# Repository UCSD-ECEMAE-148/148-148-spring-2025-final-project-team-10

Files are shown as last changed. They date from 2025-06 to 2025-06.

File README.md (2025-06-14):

# Autonomous Driving with Ultra-Wide Band (UWB) and Aruco Marker

<div align="center">
  <a href="https://jacobsschool.ucsd.edu/">
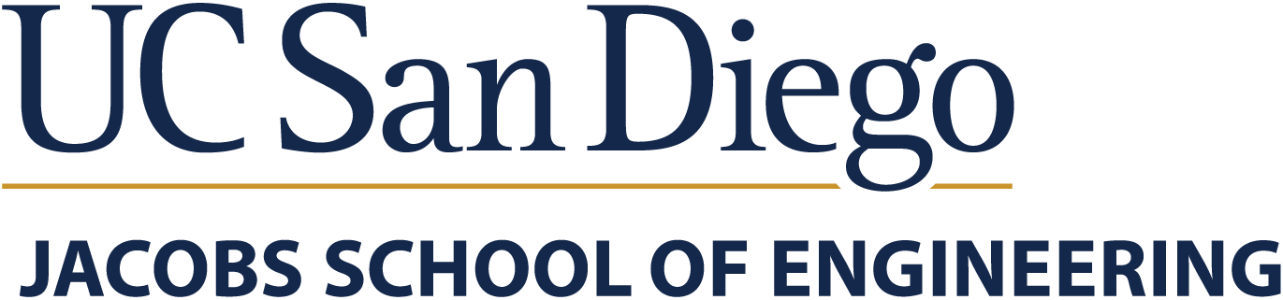
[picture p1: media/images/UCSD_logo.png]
    
  </a>
  <h3>ECE/MAE-148 Final Project</h3>
  <p>
    Spring 2025 - Team 10
  </p>
  <a>
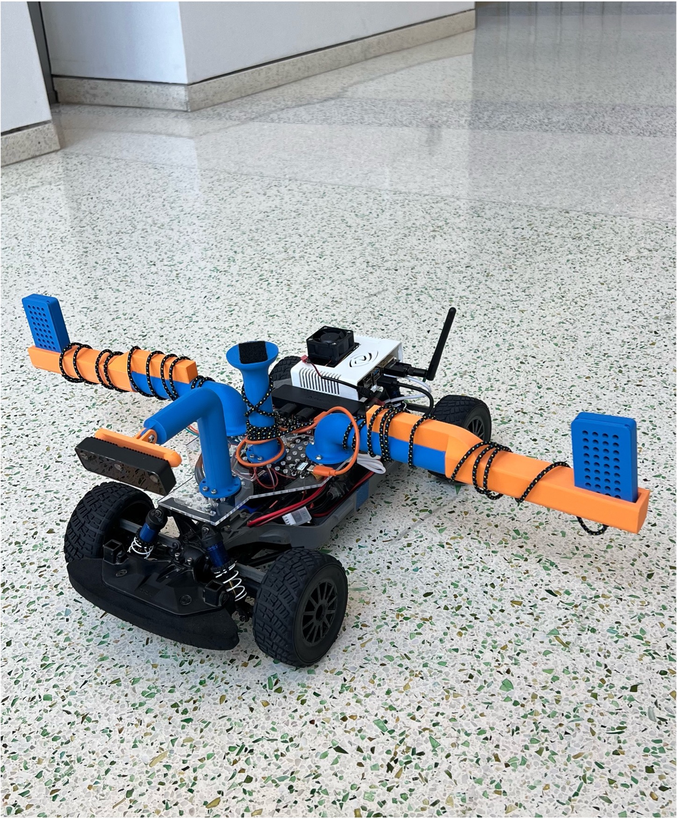
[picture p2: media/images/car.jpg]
Car View
    
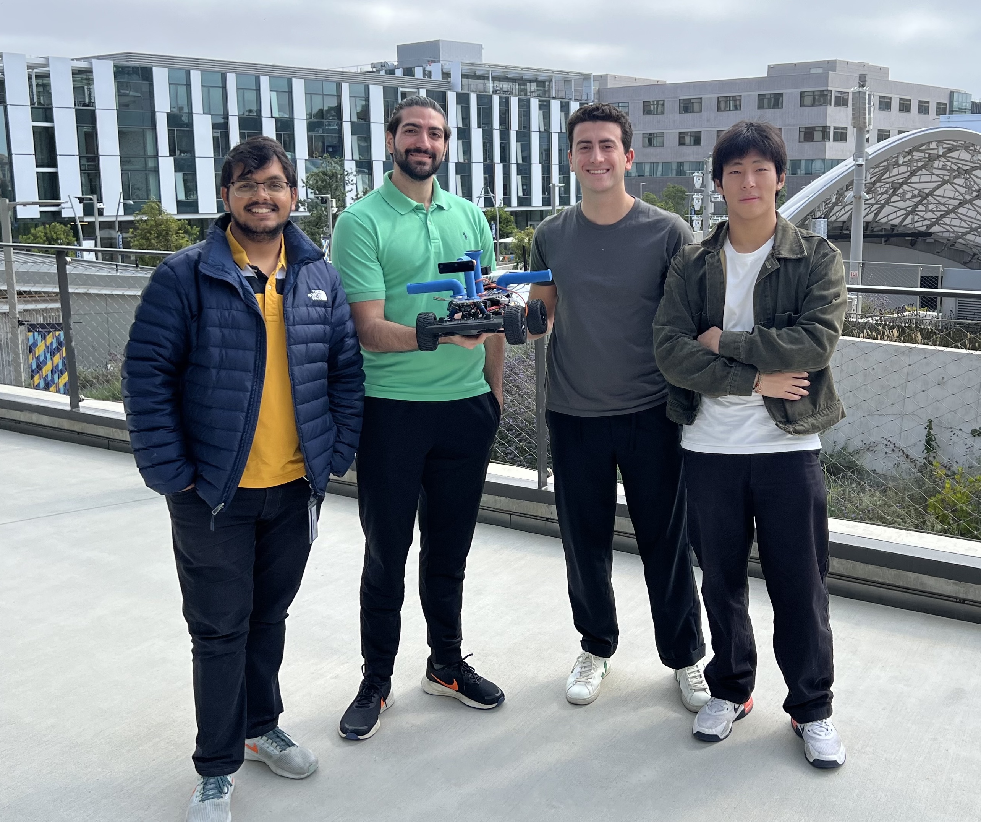
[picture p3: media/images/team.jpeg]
Team-10 Group Photo
    

  </a>
</div>

<details>
  <summary>Table of Contents</summary>

  - [Team Members](#team-members)
  - [Abstract](#abstract)
  - [Goals](#goals)
    - [Must Have](#must-have)
    - [Nice to Have](#nice-to-have)
  - [Accomplishments](#accomplishments)
  - [Challenges Faced](#challenges-faced)
  - [Step-by-Step Running Instructions](#step-by-step-running-instructions)
    - [Hardware Setup](#hardware-setup)
    - [Software Setup](#software-setup)
    - [Plotting Live Location from ESP32](#plotting-live-location-from-esp32)
    - [Driving the Car with ESP32](#driving-the-car-with-esp32)
    - [Driving the Car with Aruco Marker](#driving-the-car-with-aruco-marker)
  - [Code Documentation](#code-documentation)
    - [Driving with ESP32](#driving-with-esp32)
    - [Driving with Aruco Marker](#driving-with-aruco-marker)
  - [Hardware Used](#hardware-used)
    - [Parts](#parts)
    - [Wiring](#wiring)
  - [Gantt Chart](#gantt-chart)
  - [Acknowledgements](#acknowledgements)
  - [Contacts](#contacts)

  </details>

## Team Members (left to right)
- **Pushkal Mishra** | ECE: PhD in Wireless Sensing and ML
- **Efe Erturk** | ECE: BS in Electrical Engineering 
- **Etka Uzun** | MAE: BS in Aerospace Engineering
- **Junran "Jason" Wang** | ECE: BS in Computer Engineering
  
## Abstract
In this project, we developed an autonomous car following system using Ultra-Wide Band (UWB) technology and Aruco markers. The system is designed to enable a car to autonomously follow a UWB-enabled ESP32 tag and identify the tag with an Aruco marker. Additionally, the car can also follow the aruco marker once it is in the field-of-view. The project integrates various hardware components: NVIDIA Jetson Nano, OAK-D Lite camera, 3 ESP32 microcontroller with UWB support and IMU sensor, to achieve real-time distance measurement and control.

The aim of the project is to detect an ESP32 tag and autonomously drive towards it using triangulation and Aruco marker detection. The car is equipped with a camera for visual recognition and two ESP32 tags for UWB communication. The system is designed to be robust, allowing the car to follow the tag even in complex environments with non line-of-sight.

## Goals
### Must Have
- Accurate position measurement using triangulation with UWB.
- IMU sensor for orientation data.
- Aruco marker detection for visual identification and driving.
- Autonomous driving towards the detected tag.

### Nice to Have
- Integrate both ESP32 and Aruco marker detection for robust following.
- Real-time following of the tag.
- LiDAR integration for obstacle avoidance.

## Accomplishments
- Successfully implemented UWB triangulation for accurate distance measurement.

https://github.com/user-attachments/assets/99eae474-88a1-4db3-a036-837bd43ad0e0

In this video, we are plotting the location of the ESP32 tag predicted in real-time using the UWB triangulation. The car is placed on a desk and the tag is continuously moved around the environment and the location of the tag is plotted in real-time from the jetson connected to a monitor. In the plot, you can see two red dots representing the tags on the car and the blue dot representing the predicted location of the tag. The car is able to accurately predict the location of the tag even when it is moved around.

- IMU sensor integration for orientation data to correct for yaw of the car.

https://github.com/user-attachments/assets/ff7656d6-d6ba-4912-a2eb-ccfd36a7f4ab

In this video, we are demonstrating the robustness of location prediction using sensor fusion with IMU and UWB triangulation. The car is placed on a stand and the tag is kept stationary. As the car is rotated around, the predicted location of the tag remains stable, demonstrating the robustness of measured angular deviation using the IMU sensor. This is crucial for accurate navigation as we need to calculate the angle that the car has rotated to accurately predict the location of the tag. 

- Car can autonomously drive to a UWB-enabled ESP32 tag even in non line-of-sight condition.

https://github.com/user-attachments/assets/731a74e7-a74d-4a91-b878-ca56320b25f8

In this video, the car autonomously detects, generates waypoints and drives towards the ESP32 tag kept on the ground. This is a line-of-sight condition where there are no obstacles in the way between the car and the tag, and the car can safely drive towards the tag. 

https://github.com/user-attachments/assets/dc13d5db-3512-4963-a193-890831c27531

In this video also the car detects the tag and drives towards it. However, this is a non line-of-sight condition where there is an obstacle in between the car and the tag, and the car generates curved waypoints around the obstacle to reach the tag.

- Aruco marker detection implemented for visual identification.

https://github.com/user-attachments/assets/7d87b73c-9c4e-48f1-9f4e-f30a59d7324a

In this video, the car detects an Aruco marker, reads the ID of the marker to confirm weather its a valid user to track, determines the location and orientation of the marker and correspoindingly drive towards the marker. The steering and rotation of the car is controlled in real-time to ensure that the car is always facing the marker and is at-least 30cm away from the marker. Also the car is able to follow the marker even when it is moving around. 

## Challenges Faced
- We were limited by low range (~15m) and sometimes we wouldn't get position data due to small antenna of the DW3000 chip. 
- Even though our individual parts worked well, our location estimation varied a lot due to added uncertanities from all of them.
- We faced issues in integrating the transition from driving with ESP32 localization and driving with Aruco marker in the donkeycar framework.
- When following the Aruco marker, ROS2 was very laggy, we faced this issue in our lane-following assignment also. Might need to use an updated Jetson or larger SD card.

## Step-by-Step Running Instructions
### Hardware Setup
- Use the provided 3D-printed parts to mount the NVIDIA Jetson Nano, OAK-D Lite camera, ESP32 tags, and IMU sensor on the car.
- Connect the two ESP32 tags, OAK-D Lite Camera, and IMU sensor to the Jetson using cables.
- Ensure that the ESP32 tags are securely mounted and connected to Jetson.
- Connect the dongle for the controller to the Jetson Nano.

### Software Setup:
- First you need to install Arduino CLI, DW3000 library and IMU on the jetson nano. This can be found in the links: [Arduino CLI](https://arduino.github.io/arduino-cli/0.35/installation/), [DW3000 Library](https://github.com/Makerfabs/Makerfabs-ESP32-UWB-DW3000) and [IMU Library](https://wiki.seeedstudio.com/XIAO_BLE/)
- Clone this repository to your local machine:
  ```bash
  git clone https://github.com/UCSD-ECEMAE-148/148-spring-2025-final-project-team-10.git
  ```
- To write the localization code to the ESP32, you can open each of the `.ino` code in `driving-with-esp32/esp32_code` directory using Arduino IDE and upload it to the ESP32 tags. To use the more reliable localization, follow the instructions [here](https://github.com/kk9six/dw3000) to upload the code present in `driving-with-esp32/esp32_code_v2` directory.
- To write the code to IMU, you can simly run the following command in Jetson's terminal:
  ```bash
  cd ./driving-with-esp32/IMUcode/
  bash compile_imu.sh
  ```
- Since we are replacing the GPS coordinates with ESP32 coordinates, we need to replace the `vehicle.py` file in the donkeycar framework with the one present in `driving-with-esp32/vehicle.py`. Use the following command to do so:
  ```bash
  cp ./driving-with-esp32/vehicle.py /home/jetson/projects/donkeycar/donkeycar/vehicle.py
  ```
### Plotting Live Location from ESP32:
- As seen in the video above, we can plot the live location of the ESP32 tag using the code present in `driving-with-esp32/location_tag.py`. 
- To run this code, use the following command:
  ```bash
  cd ./driving-with-esp32/
  python3 location_tag.py
  ```
- Make sure that the thrid ESP32 anchor is connected to a power bank.
### Driving the Car with ESP32:
- To drive the car using ESP32 triangulation, you can simply run the GPS code. Run the following command in the Jetson Terminal:
  ```bash
  cd ./driving-with-esp32/
  python3 manage.py drive
  ```
- Steps to run the car:
  - First, press the "B" button to reset the IMU readings.
  - Then, press "Y" to generate the waypoints to the ESP32 tag.
  - Then, press "X" to load the path.
  - Finally press the "Start" button to start driving the car towards the ESP32 tag.
- The above key mappings can be found in `driving-with-esp32/myconfig.py`.

### Driving the Car with Aruco Marker:
- Follow the [ECE/MAE 148 document](https://docs.google.com/document/d/1Onft0sIWhEd9UH7fItJ0atC1hKnxpTxKKmUFHtqC-sA/edit?tab=t.0) (Section 4) to pull the Robocar Docker Image and set it up with ROS2

- Now create and launch Docker container:
```bash
robocar_docker test_container
docker start test_container
docker exec -it test_container bash
```
- Create ROS2 Package for Aruco
```bash
cd ~/ros2_ws/src
ros2 pkg create --build-type ament_python aruco_marker --dependencies rclpy sensor_msgs geometry_msgs std_msgs
```
- Then clone your Python node scripts:
```bash
cd aruco_marker
mkdir aruco_marker
cd aruco_marker

git clone https://github.com/UCSD-ECEMAE-148/148-spring-2025-final-project-team-10/blob/main/aruco_marker/aruco_marker/oakd_aruco_node.py oakd_aruco_node.py
git clone https://github.com/UCSD-ECEMAE-148/148-spring-2025-final-project-team-10/blob/main/aruco_marker/aruco_marker/vesc_twist_node.py esc_twist_node.py
git clone https://github.com/UCSD-ECEMAE-148/148-spring-2025-final-project-team-10/tree/main/aruco_marker/aruco_marker/vesc_submodule vesc_submodule
```
- Make sure to copy the setup and launch files from the repository to the correct directories:
  - The setup.py file is located here: [https://github.com/UCSD-ECEMAE-148/148-spring-2025-final-project-team-10/blob/main/aruco_marker/setup.py](https://github.com/UCSD-ECEMAE-148/148-spring-2025-final-project-team-10/blob/main/aruco_marker/setup.py)

  - The Launch File for both nodes are present here: [https://github.com/UCSD-ECEMAE-148/148-spring-2025-final-project-team-10/blob/main/aruco_marker/launch/duo_nodes.launch.py](https://github.com/UCSD-ECEMAE-148/148-spring-2025-final-project-team-10/blob/main/aruco_marker/launch/duo_nodes.launch.py)

- Run the following commands to build, source, and launch (from inside docker):
```bash
source_ros2
cd ~/ros2_ws
colcon build
source install/setup.bash
ros2 launch aruco_marker duo_node_.launch.py
```
- You can also use the bash script to compile and run the ROS2 nodes for faster prototyping located [here](https://github.com/UCSD-ECEMAE-148/148-spring-2025-final-project-team-10/blob/main/aruco_marker/run_ros2.sh):
```bash
bash run_ros2.sh
```

## Code Documentation
### Driving with ESP32
The directory `driving-with-esp32` contains all the code needed to drive the car. This part of the project is divided into three parts:
1. **ESP32 Distancing**: 
  - Before we can get to estimating coordinates of the tag, we first need to measure distance between two tags. 
  - Below image shows the parameters and timing measurements we need to take care of while measuring distance:
    <div align="center">
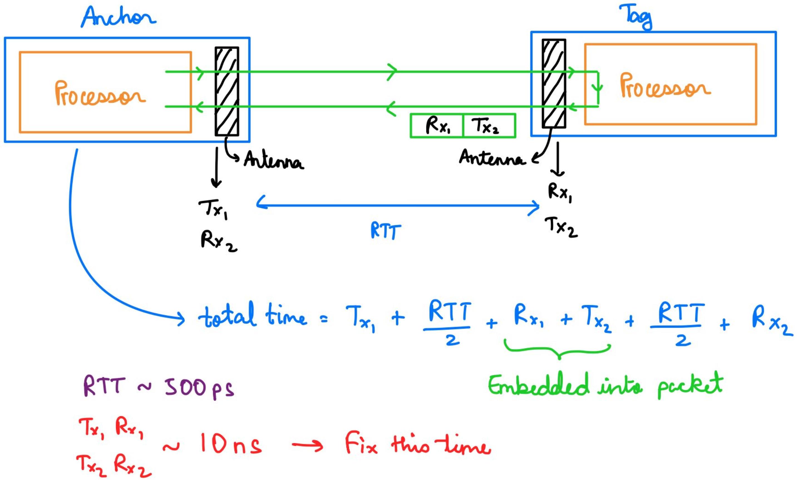
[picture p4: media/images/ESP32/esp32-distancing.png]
ESP32 Distance Measurement
      
    </div>
  - In the above image, the anchor sends a packet to the tag, which then sends a response back to the anchor. 
  - The anchor measures the time taken for the round trip and calculates the distance using the speed of light.

2. **Communication between ESP32**: 
  - For determining position of the tag, we need two tags on the car which calls for developing a communication protocol between the two ESP32 tags. 
  - The protocol is summarized in the below image:
    <div align="center">
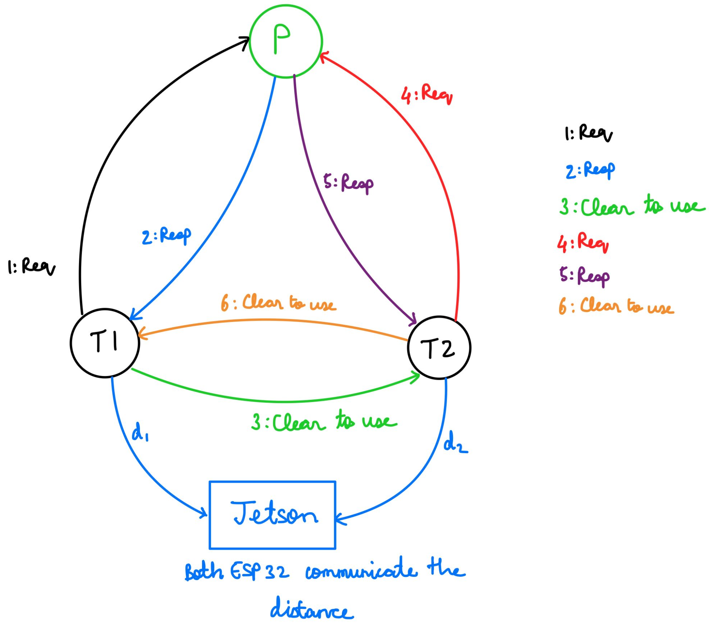
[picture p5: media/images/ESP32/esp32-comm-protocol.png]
ESP32 Communication Protocol
      
    </div>
  - This can be summarized as follows:
    - First the tag T1 sends a request packet for distancing to the anchor P.
    - The anchor P then sends a response packet to T1. T1 measures the time taken for the response and calculates the distance to the anchor.
    - T1 sends a clearance packet to T2, which is the second tag on the car.
    - T2 then sends a request packet to the anchor P.
    - The anchor P then sends a response packet to T2. T2 measures the time taken for the response and calculates the distance to the anchor.
    - T2 then sends a clearance packet to T1, which is the first tag on the car.
  - The code for Part 1 and 2 are written through arduino and can be found in the directory: `driving-with-esp32/esp32_code_v2`.
  - We were facing a lot of issues with the precision of the distance measurements, so we used the code from this repository: [https://github.com/kk9six/dw3000](https://github.com/kk9six/dw3000). We made a few modifications for our setup, which can be found in `driving-with-esp32/`.

3. **ESP32 Triangulation**: 
  - We mounted two ESP32 tags on the car which will measure the distance to a thrid ESP32 anchor placed in the environment. 
  - The image below shows the triangulation algorithm used to determine the coordinates of the tag:
    <div align="center">
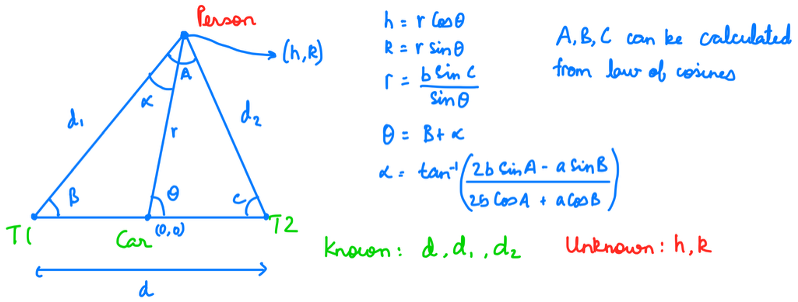
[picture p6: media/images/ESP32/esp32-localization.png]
Triangulation Algorithm
      
    </div>
  - Using this formula, we can calculate the coordinates of the tag using the distances measured by the two ESP32 tags on the car. 
  - The code for this part is in `driving-with-esp32/location_tag.py`.
    
4. **IMU Integration**:
  - We are using nRF52840 Sense IMU with 6 DOF, which supports acceleration and gyroscope data in x, y, z axes.
  - This figure shows the change in angular acceleration of as the IMU is rotated:
    <div align="center">
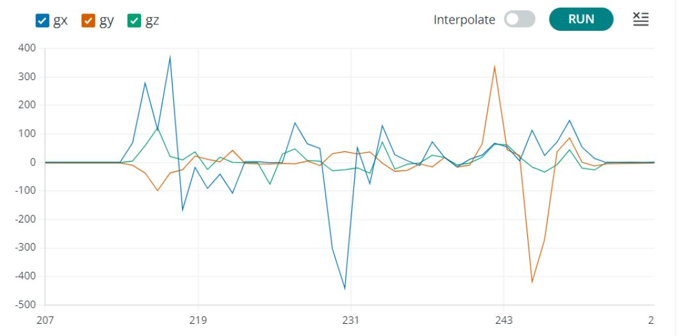
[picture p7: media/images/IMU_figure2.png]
IMU Integation
      
    </div>
  - The Z-axis gyroscope data (gz) is used to estimate the yaw angle (rotation around the vertical axis) by integrating angular velocity over time.
  - The yaw is normalized to a 0–360° range and transmitted to the jetson via serial monitor every 50 ms.
    
5. **ESP32-IMU Fusion**: 
  - As the orientation of the car changes when it drives towards the tag, the reference coordinate for distance and angle measurements also changes. 
  - This effect can be seen in the below image, where the left diagram is the case when the car does not rotate and the right diagram is the case when the car rotates:
    <div align="center">
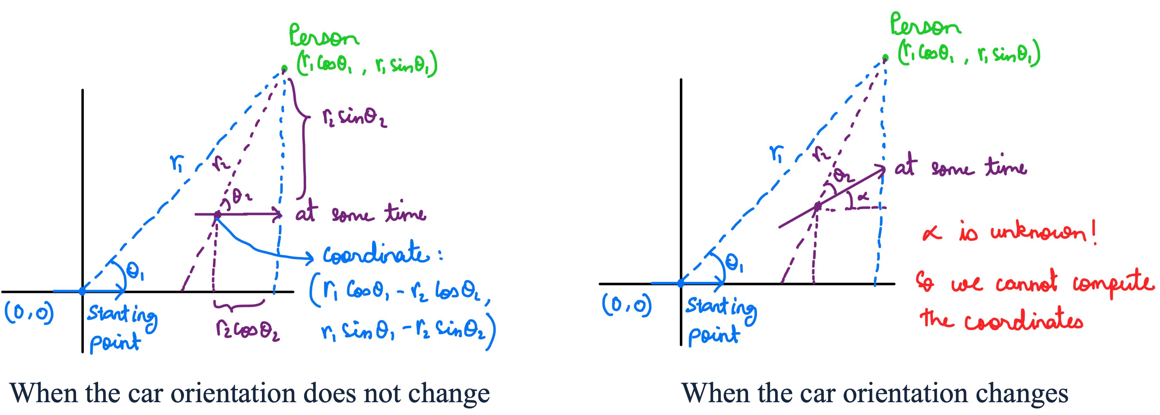
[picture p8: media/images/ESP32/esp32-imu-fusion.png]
ESP32 IMU Fusion
      
    </div>
  - To cancel out this effect, we used an IMU sensor to compute the yaw of the car and correct the coordinates of the tag accordingly.
  - The code for this part is written through arduino and can be found in the directory: `driving-with-esp32/IMUcode`.

6. **Waypoint Generation**:
  - For the car to drive towards the tag, we need to generate waypoints for the car to follow.
  - We have generated two types of paths, one is linear and the other is a curved path. These can be seen in the below image:
    <div align="center">
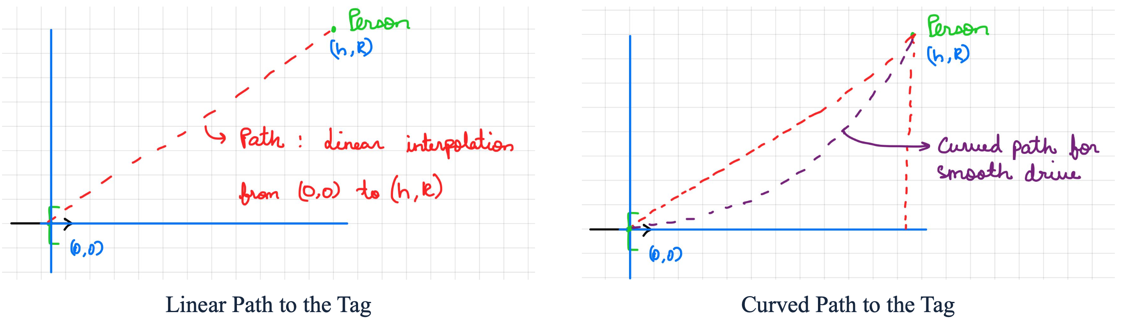
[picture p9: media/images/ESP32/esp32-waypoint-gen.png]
ESP32 Waypoints
      
    </div>
  - The curved path is basically a quadratic equation in such a manner that it passes through the tag and the car's initial position. The curvature of this path can be controlled by the parameter `PATH_CURVE_FACTOR` in `driving-with-esp32/myconfig.py`.
  - A higher path curve factor will result in a lesser curvature.

7. **Driving with ESP32**: 
  - Once we have the accurate coordinates of the tag, we used the GPS Donkeycar framework to drive the car towards the tag.
  - First we generate the waypoints for the car to the tag, and then pass this to the GPS Donkeycar framework to drive the car.
  - The code for this part is present in: `driving-with-esp32/manage.py`.
  - Further, we replaced the positions dumped by the GPS with the positions predicted by the ESP32 triangulation algorithm. This part of the code is present in `driving-with-esp32/vehicle.py`. Please note that this code should be put in the `donkeycar` directory of the donkeycar framework.

### Driving with Aruco Marker
The directory `home/projects/ros2_ws/src/aruco_marker` contains all the code needed to drive the car autnomously using aruco marker. This part of the project is divided into two parts:
1. **oakd_aruco_node.py**
- This node uses an OAK-D camera to detect Aruco markers and estimate their 3D position and orientation.
- This node file allow evey aruco marker to be considered as valid marker.
- You can generate your own marker using the OpenCV Aruco library.
- Aruco marker size is known (14 cm), allowing `cv2.aruco.estimatePoseSingleMarkers()` to calculate the translation vector (tvec) and rotation vector (rvec).
- Make sure the printed marker size is near 14cm by 14cm.
  <div align="center">
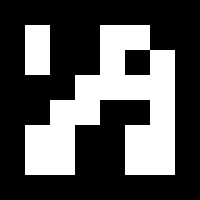
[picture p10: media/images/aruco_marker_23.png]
Aruco Marker Image
    
  </div>
- From the translation vector, we extract the following parameters from the aruco marker detection:
  - z = forward distance (used to determine rpm)
  - x = horizontal offset (used to compute steering value)
- The node converts yaw angle in radians into angular.z  and forward distance into linear.x, then publishes them in a Twist Interface
- Publishes Twist messages to ```/cmd_vel``` topic so that other node files can subscribe the motot value in this topic.
- Stops publishing if the detected marker is too close.
- Publishing 0.5 steering (center) and 0 rpm if not detecting any markers, 

2. **Running the oakd_aruco_node.py**
- run it with ```bash run_ros2.sh```
- Then on the terminal there should be distance and angle message printing. Show the aruco marker in front of the oakd camera, and the value should be changing.
- The maximum range line of sight of the camera is roughly -20 to +20 degrees, but it is kind of unstable when the marker get close to 20 degree offset.

3. **Checking if the message is published to the topic**
- run ```ros2 topic echo /cmd_vel``` on a separate terminal, then you should see linear.x and angular.z being published to the topic.

4. **vesc_twist_node.py**
- This node subscribes to /cmd_vel and controls the VESC motor and steering via the vesc_submodule:
- Converts linear.x (distance) into throttle (RPM), clamped between minimum and maximum values.
- Converts angular.z (yaw angle) from radians to degrees, and remaps to a steering servo PWM value between 0.0 and 1.0.
- Applies polarity and remapping parameters (tunable via ROS parameters).
- Commands are sent to the VESC over UART.

5. **Common issue**
- If launching the node files result in "could not connect to vesc" please re-run the bash script to debug. Vesc sometimes break down magically and re-running it can fix the issue.
- Check if VESC and Camera is plugeged directly into jetson.
- Check battery voltage level, this can cause any issue.
- If you feel like running the bash script does not make a change to the behavior, check the memory storage usage on the SD card.
- If docker break down such as xeyes not responding, quit the docker, stop the docker, then exit jetson, reboot jetson, re-ssh, restart docker, try xeyes again. If this does not solve the issue, turn off jetson and give it a couple minutes then continue working later.
- If VESC behave weirdly, please use the VESC tool to re-tune the VESC.

6. **Future potential**
- PID implementation for aruco marker autonomous driving.
- Improved pre-collision braking system using LiDar by creating another node file to publish more up-to-time distance.
- Modify ```vesc_twist_node.py``` to include the pre-collison braking algorithm.

## Hardware Used
### Parts
| Part | Preview  |  File |
|---|---|---|
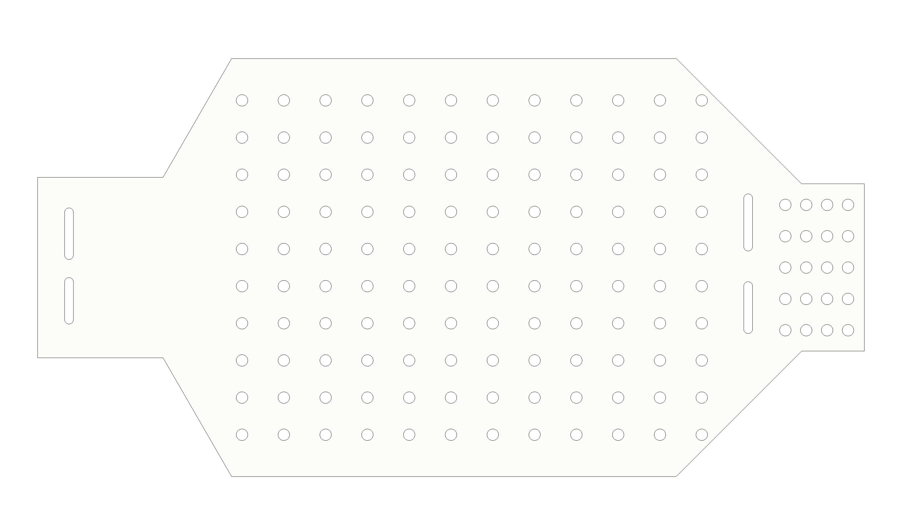
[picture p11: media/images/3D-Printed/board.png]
Mounting-board render
| **Mounting Board** |  | [DXF](media/stl-files/Electronics%20Mount%20Plate%20v1.dxf) |
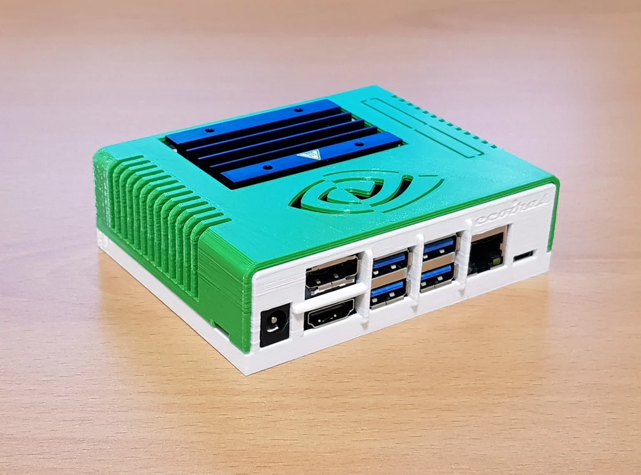
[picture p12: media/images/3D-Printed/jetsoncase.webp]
Jetson Nano case
| **NVIDIA Jetson Nano Case** |  | [Bottom STL](media/stl-files/NanoBox_Bottom_v21.stl) • [Top STL](media/stl-files/NanoBox_Top_v22.stl) |
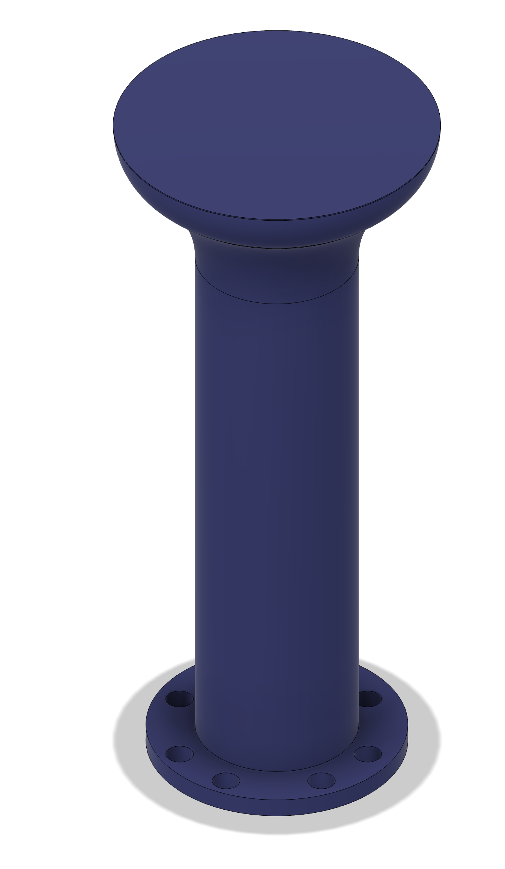
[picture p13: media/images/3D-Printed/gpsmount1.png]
GPS mount
| **GPS Mount** |  | [STL](media/stl-files/gps_mount.stl) |
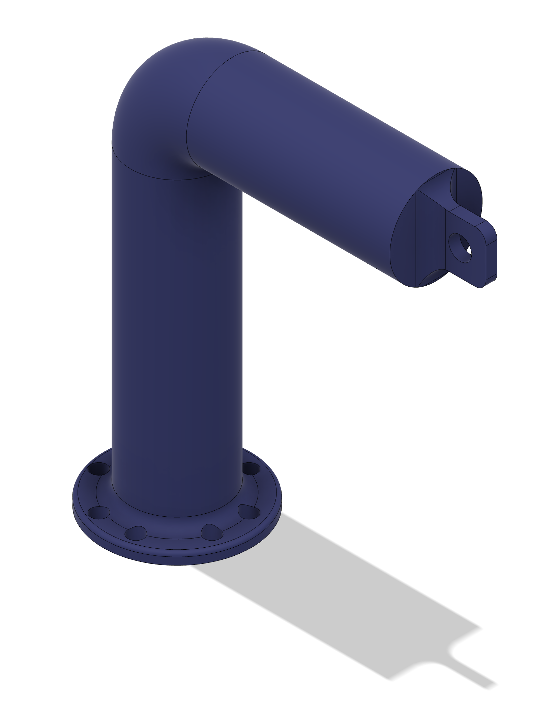
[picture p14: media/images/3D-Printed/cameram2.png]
Camera mount view 1
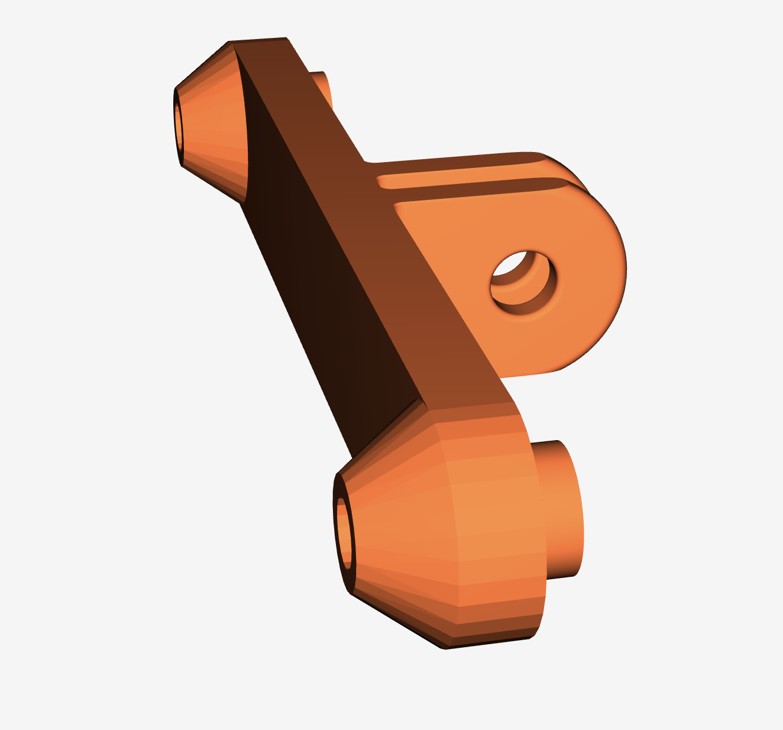
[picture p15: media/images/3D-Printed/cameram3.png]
Camera mount view 2
| **Oak-D Lite Camera Mount** | <br> | [Mount STL](media/stl-files/camera_mount.stl) • [Adapter 3MF](media/stl-files/OAK-DLiteAdapter.3mf) |
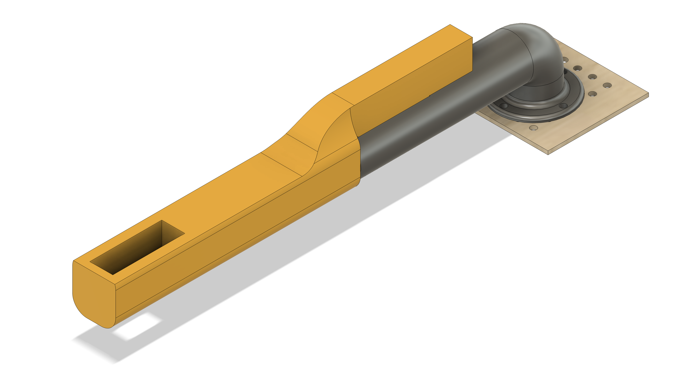
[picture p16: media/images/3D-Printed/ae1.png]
| **ESP32 Mount** |  | |
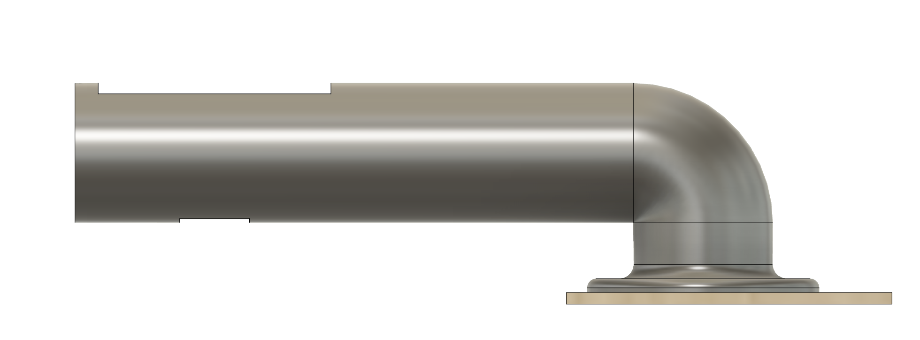
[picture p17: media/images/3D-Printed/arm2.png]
| **ESP32 Mount – Arm** |  | [STL](media/stl-files/arm.stl) |
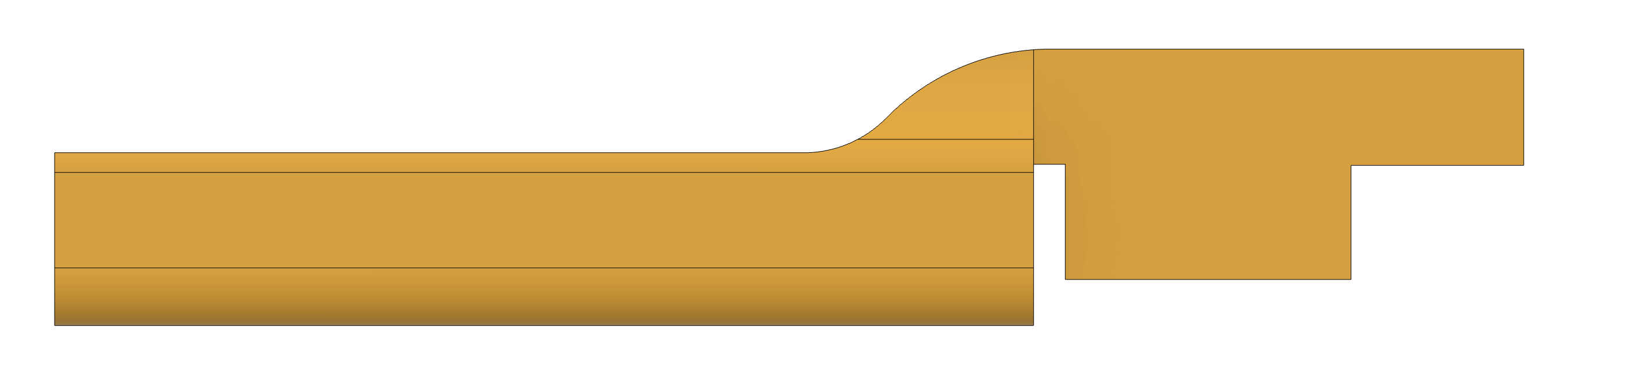
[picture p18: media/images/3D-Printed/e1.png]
ESP32 extension
| **ESP32 Mount – Extension** |  | [STL](media/stl-files/extension.stl) |
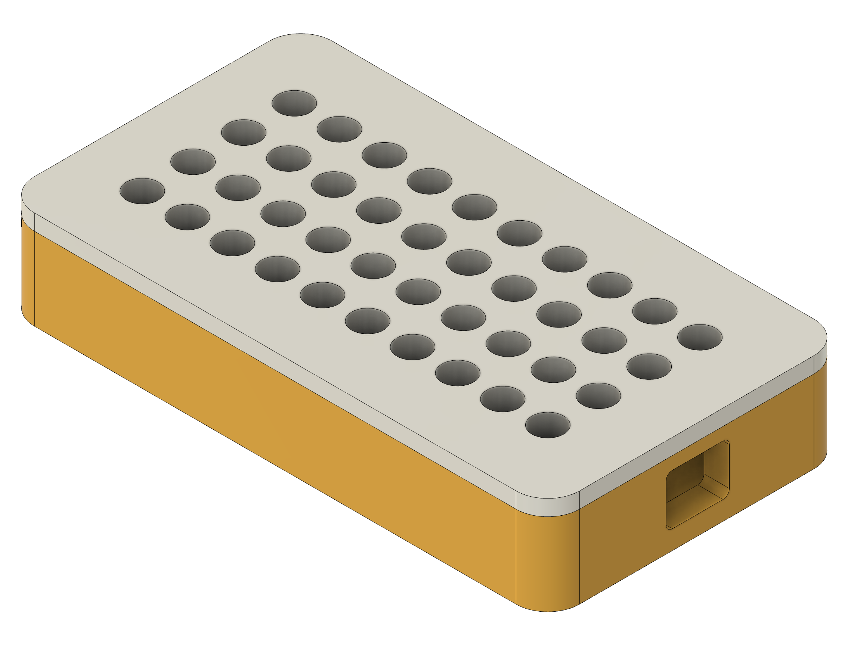
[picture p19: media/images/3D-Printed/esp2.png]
ESP32 case
| **ESP32 Case** |  | [STL](media/stl-files/esp_case_2.stl) |
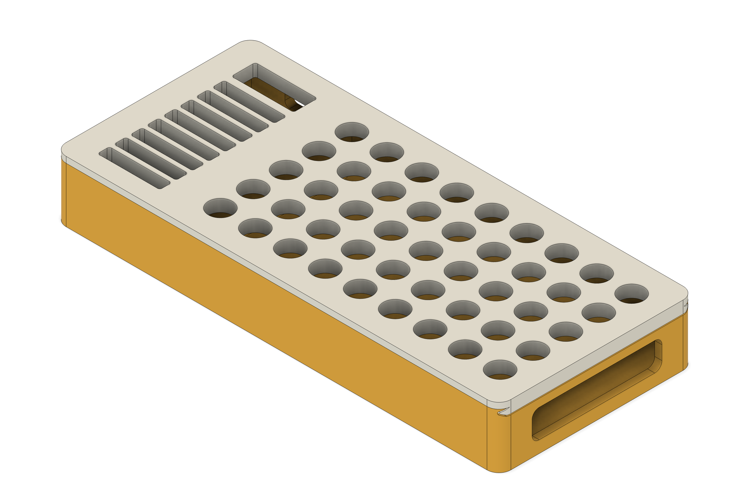
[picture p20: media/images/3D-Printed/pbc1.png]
Power-bank case
| **Power-Bank & ESP32 Case** |  | [Bottom STL](media/stl-files/power_bank_case_1.stl) • [Top STL](media/stl-files/power_bank_case_2.stl) |
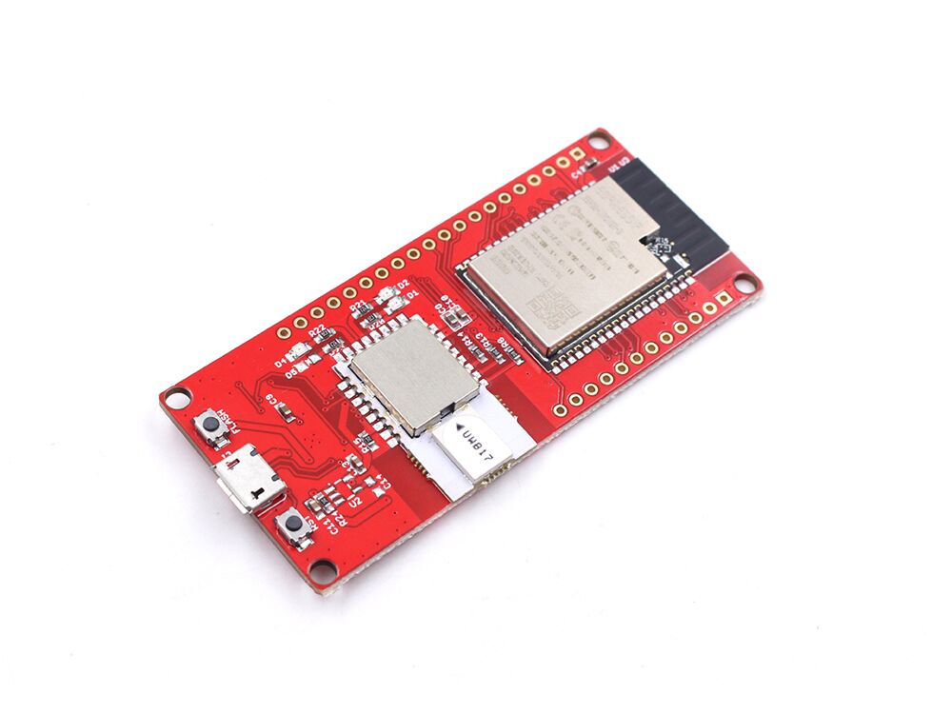
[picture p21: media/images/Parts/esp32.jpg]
| **ESP32 with UWB** |  | [Product Link](https://www.makerfabs.com/esp32-uwb-dw3000.html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) |
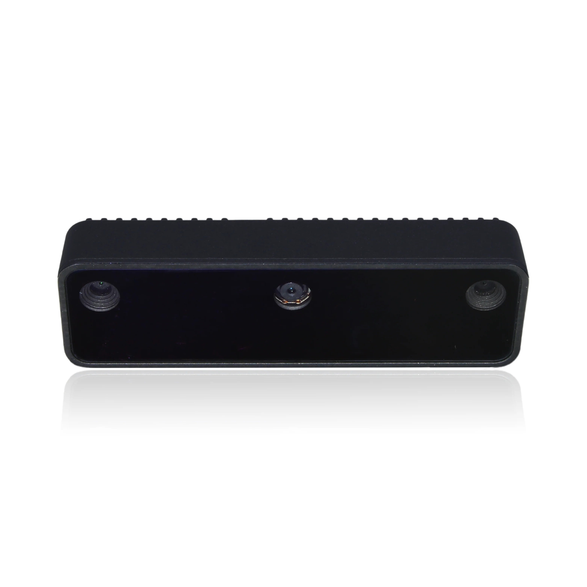
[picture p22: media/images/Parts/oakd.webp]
| **OAK-D Camera** |  | [Product Link](https://shop.luxonis.com/products/oak-d-lite-1?variant=42583102456031) |
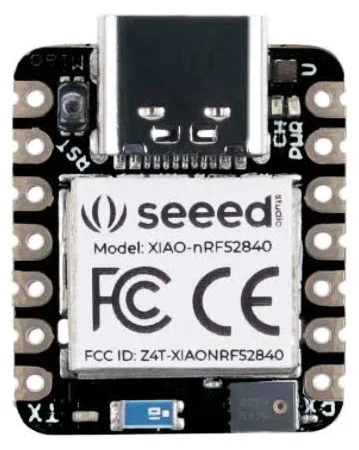
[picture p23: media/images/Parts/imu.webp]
| **IMU** |  | [Product Link](https://wiki.seeedstudio.com/XIAO_BLE/) |
| **Logitech Controller** | ESP-32 | [Product Link](https://www.logitechg.com/en-us/products/gamepads/f710-wireless-gamepad.940-000117.html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) |

### Wiring
<div align="center">
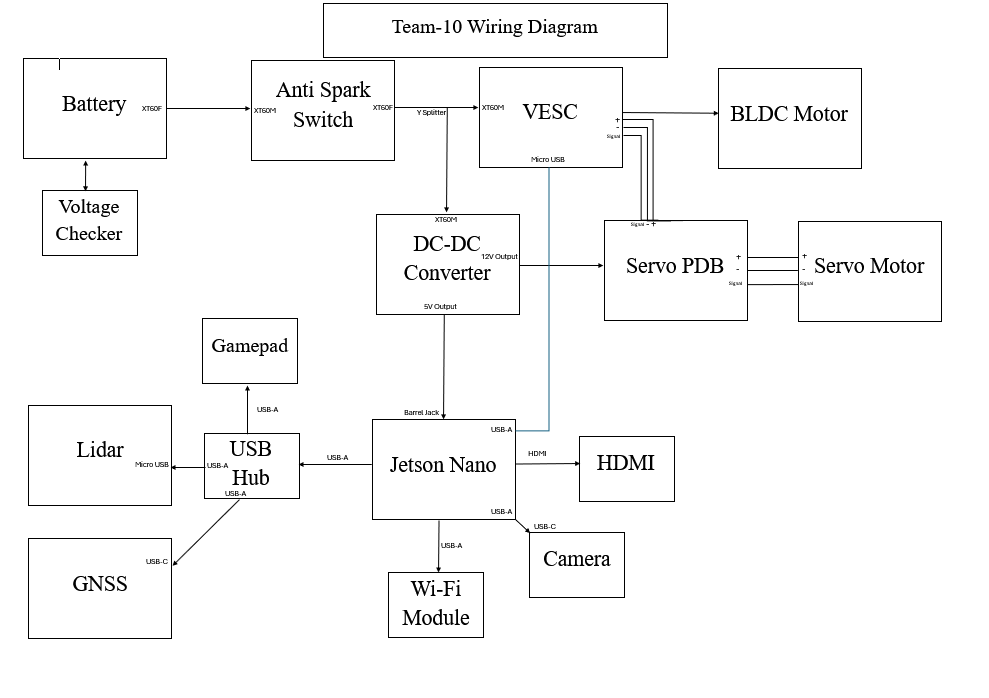
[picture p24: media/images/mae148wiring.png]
Wiring
  
</div>

## Gantt Chart
<div align="center">
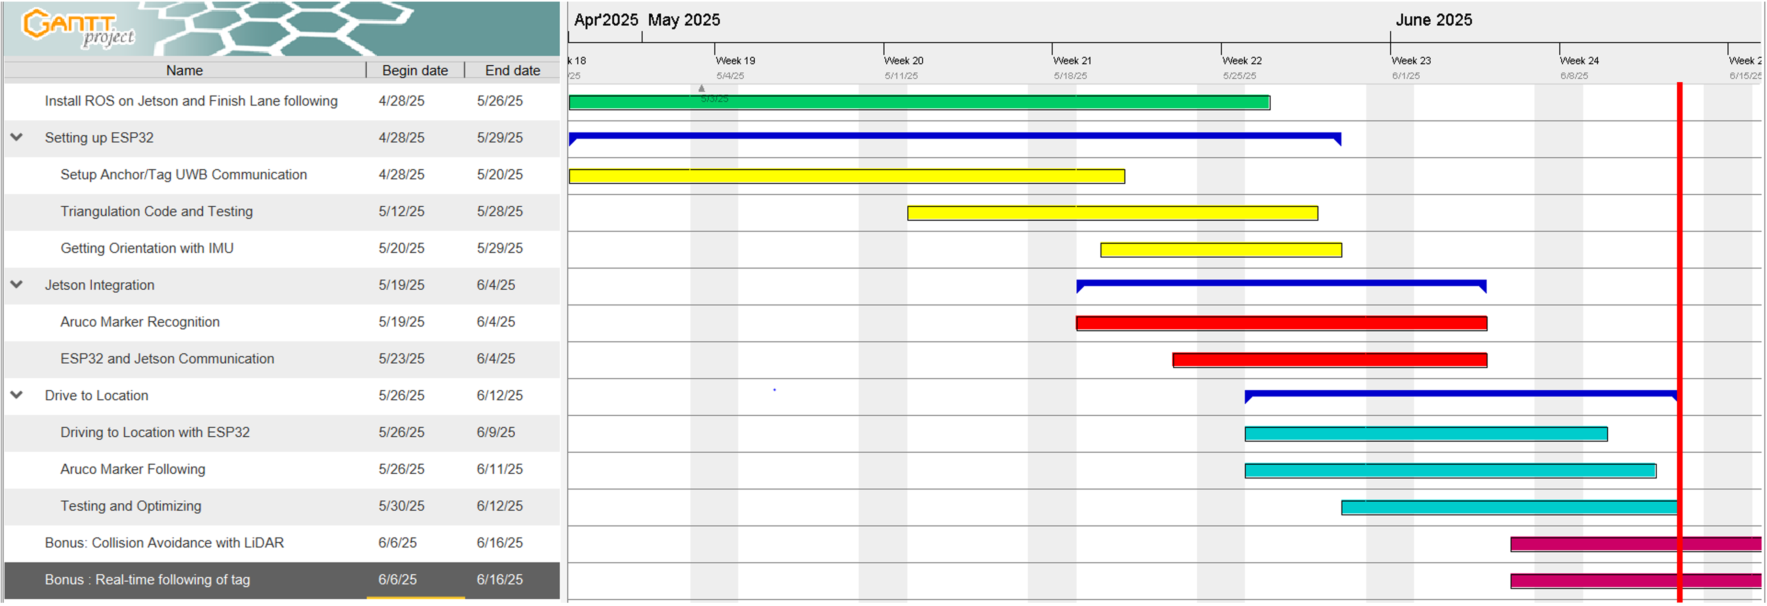
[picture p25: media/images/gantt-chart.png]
Gantt Chart
  
</div>

## Acknowledgements
Special thanks to Professor Jack Silberman and our TAs, Alex and Winston for the continous support and guidance throughout the quarter.

## Contacts
- Pushkal Mishra (pumishra@ucsd.edu)
- Efe Erturk (eerturk@ucsd.edu)
- Jason Junran (juw070@ucsd.edu)
- Etka Uzun (muzun@ucsd.edu)

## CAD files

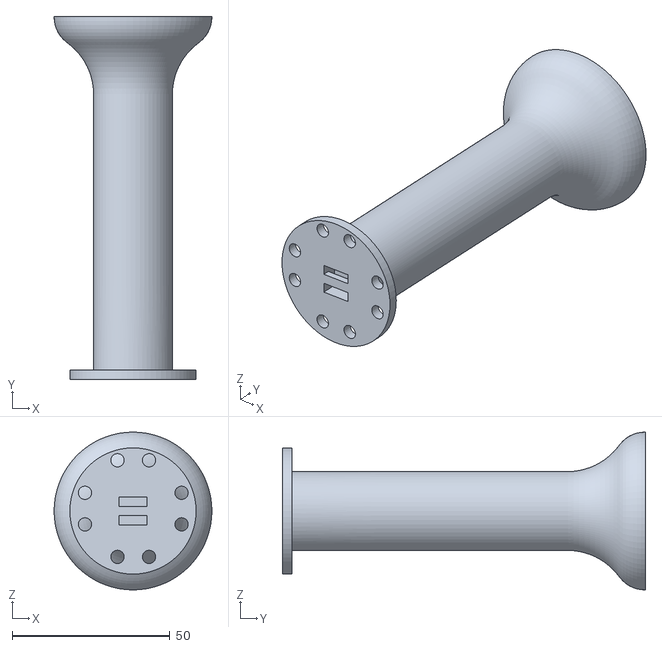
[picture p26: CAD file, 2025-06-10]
media/stl-files/gps_mount.stl
50.0 x 115.0 x 50.0

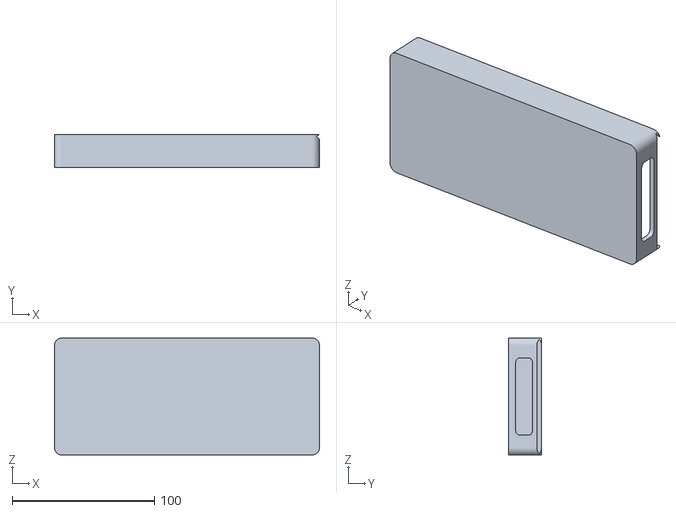
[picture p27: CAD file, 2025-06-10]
media/stl-files/power_bank_case_1.stl
186.0 x 23.0 x 82.0

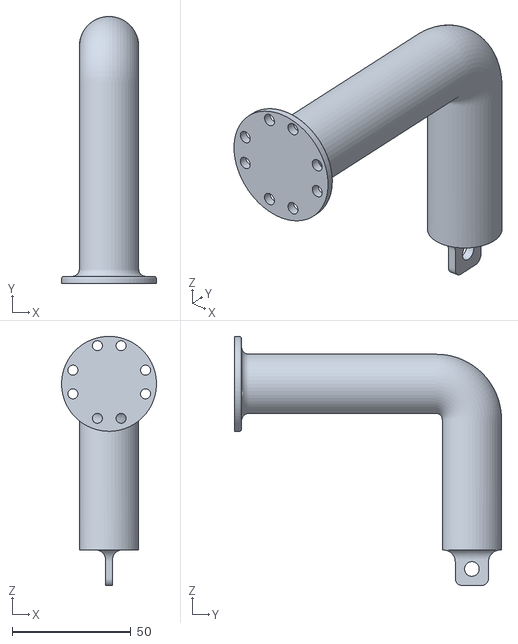
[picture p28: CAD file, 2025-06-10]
media/stl-files/camera_mount.stl
40.0 x 112.5 x 105.0

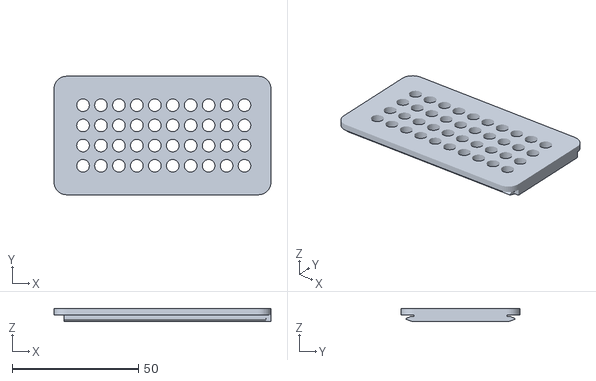
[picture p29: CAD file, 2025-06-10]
media/stl-files/esp_case_2.stl
86.0 x 47.0 x 5.00

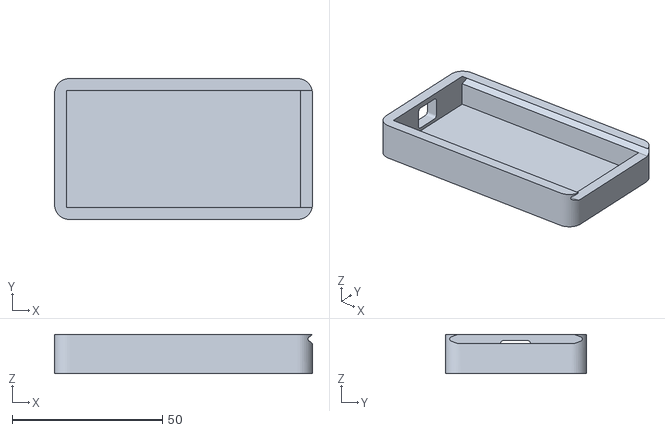
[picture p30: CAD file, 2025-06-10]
media/stl-files/esp_case_1.stl
86.0 x 47.0 x 13.0

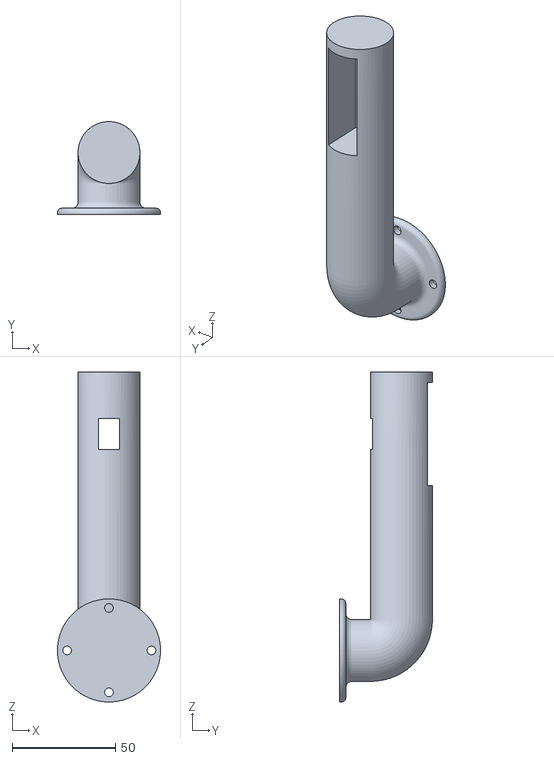
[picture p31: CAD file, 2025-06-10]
media/stl-files/arm.stl
50.0 x 45.0 x 160.0

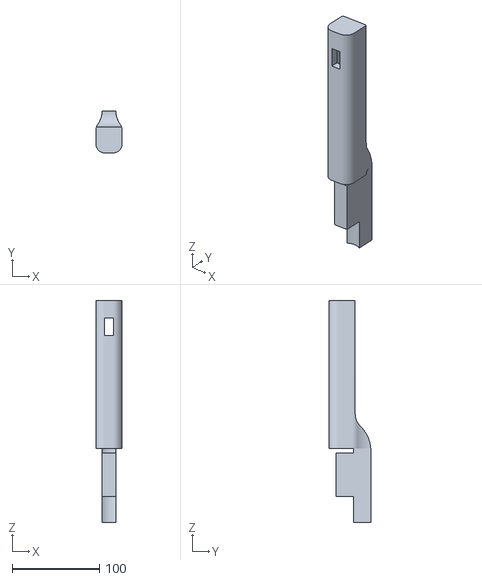
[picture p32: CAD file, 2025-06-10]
media/stl-files/extension.stl
30.0 x 48.0 x 255.1

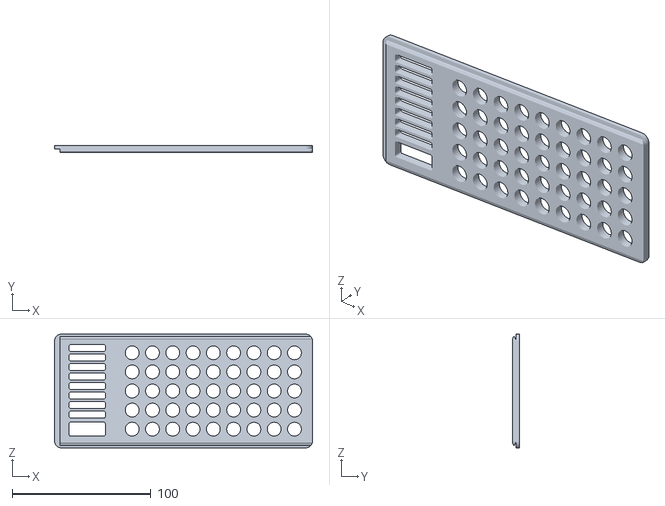
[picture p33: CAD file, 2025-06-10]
media/stl-files/power_bank_case_2.stl
186.0 x 5.10 x 82.0

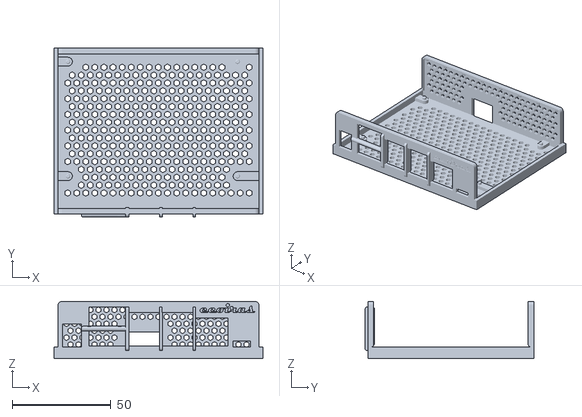
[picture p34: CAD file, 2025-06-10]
media/stl-files/NanoBox_Bottom_v21.stl
105.9 x 85.8 x 29.0

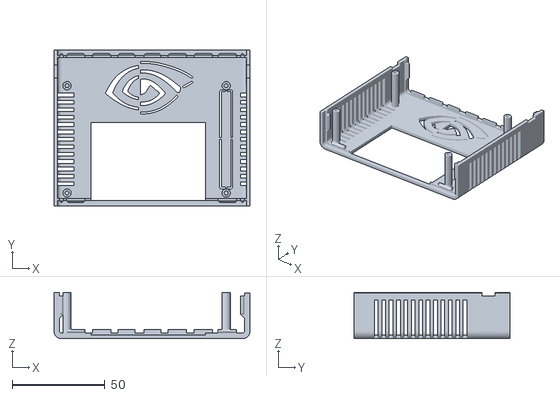
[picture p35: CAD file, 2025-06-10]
media/stl-files/NanoBox_Top_v22.stl
105.9 x 84.3 x 25.0

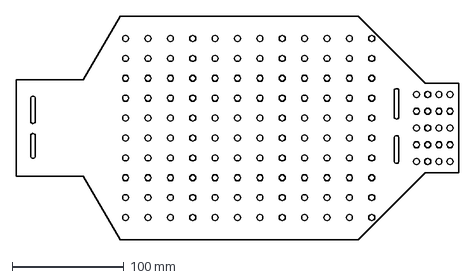
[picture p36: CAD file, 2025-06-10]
media/stl-files/Electronics Mount Plate v1.dxf
395.6 x 200.0 mm

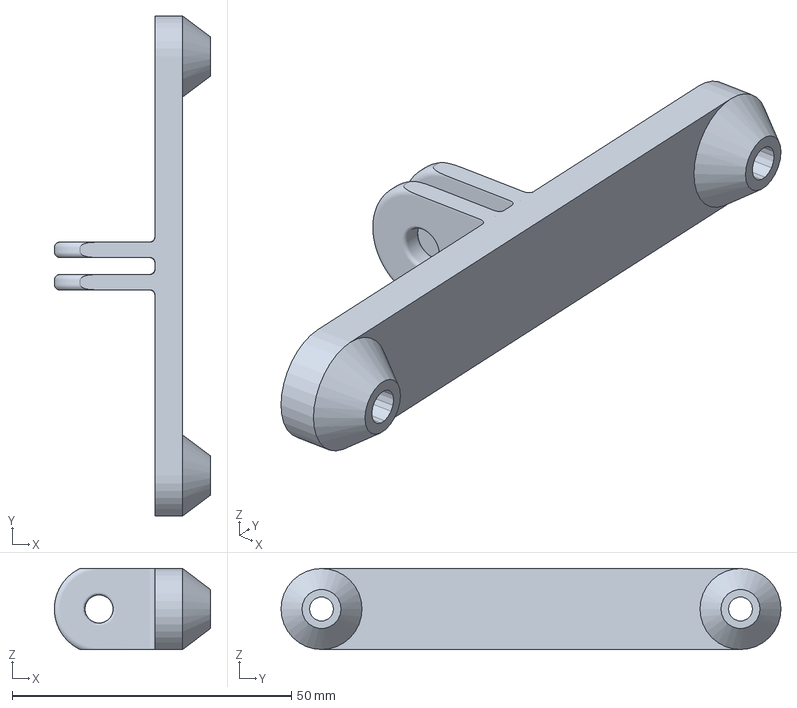
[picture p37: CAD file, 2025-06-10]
media/stl-files/OAK-DLiteAdapter.3mf
28.0 x 89.5 x 14.5 mm

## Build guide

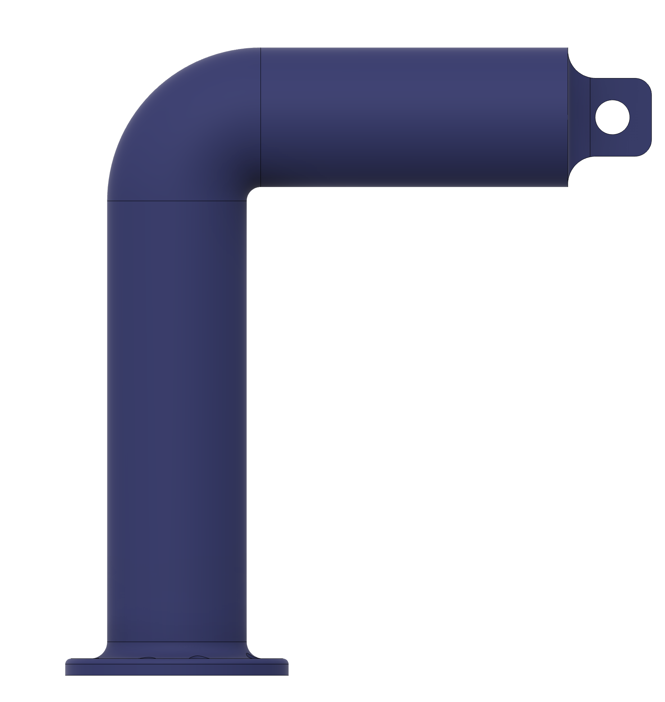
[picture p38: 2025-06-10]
media/images/3D-Printed/cameram1.png

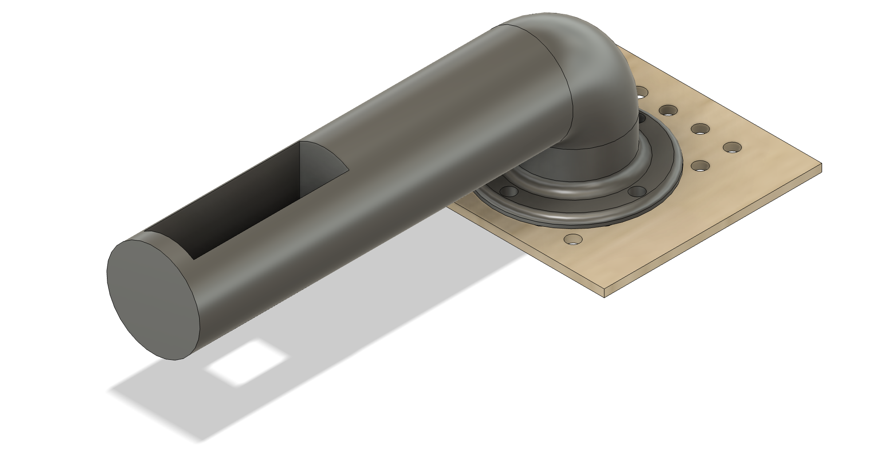
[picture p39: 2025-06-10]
media/images/3D-Printed/arm1.png

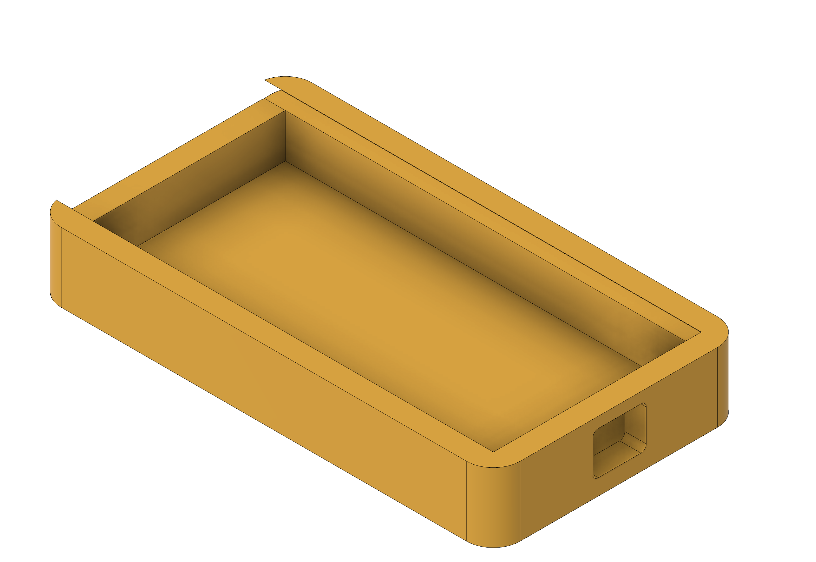
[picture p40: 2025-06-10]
media/images/3D-Printed/esp1.png

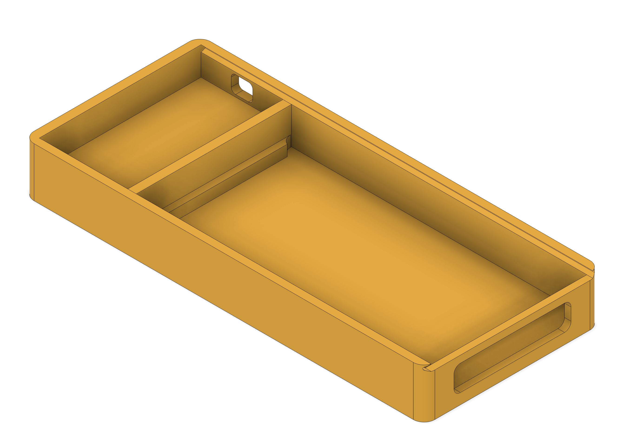
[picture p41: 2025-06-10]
media/images/3D-Printed/pbc2.png

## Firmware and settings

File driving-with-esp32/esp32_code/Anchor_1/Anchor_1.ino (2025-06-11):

#include "dw3000.h"
#include <Arduino.h>

// Constants
#define DEVICE_ID 0
#define OTHER_ANCHOR_ID 1
#define TAG_ID 2
#define FCS_LEN 2
#define MSG_LEN 20
#define TIMING_OFFSET_CONST 0.999990698
// ToF: 31714280 - Processing Time: 31714425.00 - Corrected ToF: -145.00

// Pin definitions
const uint8_t PIN_RST = 27;
const uint8_t PIN_IRQ = 34;
const uint8_t PIN_SS = 4;

// Global variables
uint32_t start_time;
static int curr_stage = 0;
uint8_t msg_index = 0;
static uint32_t status_reg = 0;
static int message_timeout = 1000; // in ms, timeout for message reception

// Buffers
static uint8_t rx_buffer[MSG_LEN];
uint32_t poll_tx_ts, resp_rx_ts;
uint8_t rx_buffer_tof_cycles[MSG_LEN];

// Variables for TWR-SS
static uint64_t tof, tag_processing_time;
static double corrected_processing_time, corrected_tof, distance;

// Constants
const double c_speed = 299702547.0; // in meters per second
const double DTU_TO_S = 1 / (128 * 499.2 * 1e6);  // 15.65 ps per DTU = 0.01565 ns
const double MEASUREMENT_INTERVAL = 10; // in ms, interval between measurements

// Configuration mode for DWT
static dwt_config_t config = {
        5,               /* Channel number. */
        DWT_PLEN_128,    /* Preamble length. Used in TX only. */
        DWT_PAC8,        /* Preamble acquisition chunk size. Used in RX only. */
        9,               /* TX preamble code. Used in TX only. */
        9,               /* RX preamble code. Used in RX only. */
        1,               /* 0 to use standard 8 symbol SFD, 1 to use non-standard 8 symbol, 2 for non-standard 16 symbol SFD and 3 for 4z 8 symbol SDF type */
        DWT_BR_6M8,      /* Data rate. */
        DWT_PHRMODE_STD, /* PHY header mode. */
        DWT_PHRRATE_STD, /* PHY header rate. */
        (129 + 8 - 8),   /* SFD timeout (preamble length + 1 + SFD length - PAC size). Used in RX only. */
        DWT_STS_MODE_OFF, /* STS disabled */
        DWT_STS_LEN_64,/* STS length see allowed values in Enum dwt_sts_lengths_e */
        DWT_PDOA_M0      /* PDOA mode off */
};

// Tx configurations
extern dwt_txconfig_t txconfig_options;

// Standard Tx and Rx messages that will be communicated
// Description:
// 0: Sender ID (0 - 1st Anchor, 1 - 2nd Anchor, 2 - Tag)
// 1: Receiver ID (0 - 1st Anchor, 1 - 2nd Anchor, 2 - Tag)
// 2: Message Number (0 - 1st Message, 1 - 2nd Message, 2 - 3rd Message, etc.)
// 3: Message Type (0 - Ping, 1 - Pong, 2 - Pong with processing time, 3 - Clearance)
// 4: Processing Time - 1 byte
// 5: Processing Time - 1 byte
// 6: Processing Time - 1 byte
// 7: Processing Time - 1 byte
// 8: Processing Time - 1 byte
// 9: Processing Time - 1 byte
// 10: Processing Time - 1 byte
// 11: Processing Time - 1 byte
// Constants to access the message fields
#define SENDER_ID_IDX 0
#define RECEIVER_ID_IDX 1
#define MESSAGE_NUMBER_IDX 2
#define MESSAGE_TYPE_IDX 3
#define START_PROCESSING_TIME_IDX 4
// Constants for message types
#define PING_MESSAGE 0
#define PONG_MESSAGE 1
#define PONG_WITH_PROCESSING_TIME_MESSAGE 2
#define CLEARANCE_MESSAGE 3

static uint8_t tx_ping_msg[] = {0, 0, 0, 0, 0, 0, 0, 0, 0, 0, 0, 0, 0, 0, 0, 0, 0, 0, 0, 0};
// static uint8_t rx_pong_msg[] = {0, 0, 0, 0, 0, 0, 0, 0, 0, 0, 0, 0, 0, 0, 0, 0, 0, 0, 0, 0};

uint64_t get_time_tx() {
    uint32_t hi32 = dwt_readtxtimestamphi32(); // bits [8..39], stored in bits [0..31] here
    uint32_t lo32 = dwt_readtxtimestamplo32(); // bits [0..31]

    // Extract the low 8 bits from lo32
    uint8_t low8 = (uint8_t)(lo32 & 0xFF);

    // Shift hi32 left by 8 bits to make space for the low 8 bits
    uint64_t timestamp = ((uint64_t)hi32 << 8) | low8;

    return timestamp;  // Full 40-bit RX timestamp
}

uint64_t get_time_rx() {
    uint32_t hi32 = dwt_readrxtimestamphi32(); // bits [8..39], stored in bits [0..31] here
    uint32_t lo32 = dwt_readrxtimestamplo32(); // bits [0..31]

    // Extract the low 8 bits from lo32
    uint8_t low8 = (uint8_t)(lo32 & 0xFF);

    // Shift hi32 left by 8 bits to make space for the low 8 bits
    uint64_t timestamp = ((uint64_t)hi32 << 8) | low8;

    return timestamp;  // Full 40-bit RX timestamp
}

void setup() {
  // Initialize serial
  UART_init();
  Serial.println("Setting up the anchor board for TWR-SS");

  // Set pins
  spiBegin(PIN_IRQ, PIN_RST);
  spiSelect(PIN_SS);

  delay(2);

  // Check if its idle or not
  while (!dwt_checkidlerc()) 
  {
    UART_puts("IDLE FAILED\r\n");
    while (1) ;
  }
  dwt_softreset();

  // Initialize the DWT board
  if (dwt_initialise(DWT_DW_INIT) == DWT_ERROR)
  {
    UART_puts("INIT FAILED\r\n");
    while (1) ;
  }

  // Enabling LEDs here
  dwt_setleds(DWT_LEDS_ENABLE | DWT_LEDS_INIT_BLINK);

  // Load the configuration into DWT
  if(dwt_configure(&config)){
    UART_puts("CONFIG FAILED\r\n");
    while (1) ;
  }

  // Applying the default Tx configuration options
  dwt_configuretxrf(&txconfig_options);

  // // Setting the delay values for Tx and Rx
  // dwt_setrxantennadelay(RX_ANT_DLY);
  // dwt_settxantennadelay(TX_ANT_DLY);

  // This is to set the transmit and receive power for better ranging
  dwt_setlnapamode(DWT_LNA_ENABLE | DWT_PA_ENABLE);
}

// Description of the stages:
// 0: Transmitting PING message for distance measurement
// 1: Waiting for message reception - PONG message
// 2: Waiting for message reception - PONG with processing time messages
// 2: Send clear message to Anchor 2 to start its distance measurement
// 3: Waiting for message reception - This contains clearance message from Anchor 2

void loop() {
  // Serial.println(curr_stage);
  switch(curr_stage) {
    case 0: {
      // Transmitting ping message
      // Setting the transmitted frame
      tx_ping_msg[SENDER_ID_IDX] = DEVICE_ID;
      tx_ping_msg[RECEIVER_ID_IDX] = TAG_ID;
      tx_ping_msg[MESSAGE_NUMBER_IDX] = msg_index;
      tx_ping_msg[MESSAGE_TYPE_IDX] = PING_MESSAGE;

      // Clear Tx status flag
      dwt_write32bitreg(SYS_STATUS_ID, SYS_STATUS_TXFRS_BIT_MASK);

      // Transmitting the data and correcting for buffer offset
      dwt_writetxdata(sizeof(tx_ping_msg), tx_ping_msg, 0);
      dwt_writetxfctrl(sizeof(tx_ping_msg), 0, 1);
      
      // Immediately start transmission along with response flag expected
      dwt_starttx(DWT_START_TX_IMMEDIATE | DWT_RESPONSE_EXPECTED);
      // Serial.println("Waiting for transmission");

      /// Waiting for transmission to complete
      while (!(dwt_read32bitreg(SYS_STATUS_ID) & SYS_STATUS_TXFRS_BIT_MASK)) {
        // Do nothing
      }
      // Activate message retrieval immediately
      dwt_rxenable(DWT_START_RX_IMMEDIATE);
      // Serial.println("Transmission complete");
      curr_stage = 1;
      break;
    }
    case 1: {
      // Waiting for message reception
      start_time = millis();
      while (!((status_reg = dwt_read32bitreg(SYS_STATUS_ID)) & (SYS_STATUS_RXFCG_BIT_MASK | SYS_STATUS_ALL_RX_ERR))) {
        if (millis() - start_time > message_timeout) {
          curr_stage = 0;
          break;
        }
      }

      if (curr_stage == 0) {
        Serial.println("Message timeout, transmitting new ping message");
        ESP.restart();
        break;
      }

      if (status_reg & SYS_STATUS_RXFCG_BIT_MASK) {
        // Compute frame length for received frame
        uint32_t frame_len;

        // Clear the good frame received flag
        dwt_write32bitreg(SYS_STATUS_ID, SYS_STATUS_RXFCG_BIT_MASK);
        
        // Reading the frame
        frame_len = dwt_read32bitreg(RX_FINFO_ID) & RXFLEN_MASK;
        if (frame_len <= sizeof(rx_buffer)) {
          // Reading the frame from Rx buffer
          dwt_readrxdata(rx_buffer, frame_len, 0);

          // If the message was sent by the tag and meant for PONG message
          if (rx_buffer[SENDER_ID_IDX] == TAG_ID && rx_buffer[RECEIVER_ID_IDX] == DEVICE_ID && rx_buffer[MESSAGE_TYPE_IDX] == PONG_MESSAGE) {
            // Record the transmit and receive timestamps for TWR-SS
            poll_tx_ts = get_time_tx();
            resp_rx_ts = get_time_rx();
            tof = resp_rx_ts - poll_tx_ts;
            curr_stage = 2;
          }
          else {
            // If the message was not meant for this anchor, clear the good frame received flag
            Serial.println("There is an error in the protocol!");
            dwt_write32bitreg(SYS_STATUS_ID, SYS_STATUS_ALL_RX_TO | SYS_STATUS_ALL_RX_ERR);
            curr_stage = 0;
          }
          // Start reception of the next message
          dwt_rxenable(DWT_START_RX_IMMEDIATE);
        }
      }
      else {
        dwt_write32bitreg(SYS_STATUS_ID, SYS_STATUS_ALL_RX_TO | SYS_STATUS_ALL_RX_ERR);
        curr_stage = 0;
      }
      break;
    }
    case 2: {
      // Waiting for message reception
      start_time = millis();
      while (!((status_reg = dwt_read32bitreg(SYS_STATUS_ID)) & (SYS_STATUS_RXFCG_BIT_MASK | SYS_STATUS_ALL_RX_ERR))) {
        if (millis() - start_time > message_timeout) {
          curr_stage = 0;
          break;
        }
      }

      if (curr_stage == 0) {
        Serial.println("Message timeout, transmitting new ping message");
        ESP.restart();
        break;
      }

      if (status_reg & SYS_STATUS_RXFCG_BIT_MASK) {
        // Compute frame length for received frame
        uint32_t frame_len;

        // Clear the good frame received flag
        dwt_write32bitreg(SYS_STATUS_ID, SYS_STATUS_RXFCG_BIT_MASK);
        
        // Reading the frame
        frame_len = dwt_read32bitreg(RX_FINFO_ID) & RXFLEN_MASK;
        if (frame_len <= sizeof(rx_buffer)) {
          // Reading the frame from Rx buffer
          dwt_readrxdata(rx_buffer, frame_len, 0);

          // If the message was sent by the tag and meant for PONG with processing time message
          if (rx_buffer[SENDER_ID_IDX] == TAG_ID && rx_buffer[RECEIVER_ID_IDX] == DEVICE_ID && rx_buffer[MESSAGE_TYPE_IDX] == PONG_WITH_PROCESSING_TIME_MESSAGE) {
            // Storing the processing time of the tag
            tag_processing_time = 0;
            for (int i = 0; i < 8; i++) {
              tag_processing_time |= ((uint64_t)rx_buffer[START_PROCESSING_TIME_IDX + i]) << (56 - 8 * i);
            }
            // tof = tof - tag_processing_time;
            // Serial.println(tof);
            // msg_index += 1;
            // curr_stage = 3;
            // // distance = tof * DWT_TIME_UNITS * SPEED_OF_LIGHT;
            // // Serial.print("Tof Adjusted: ");
            // // Serial.print("Distance: ");
            // // Serial.println(distance);
            
            corrected_processing_time = tag_processing_time * TIMING_OFFSET_CONST;
            // corrected_processing_time = tag_processing_time;
            corrected_tof = tof - corrected_processing_time;
            
            // Serial.print("ToF: ");
            // Serial.print(tof);
            // Serial.print(" - Processing Time: ");
            // Serial.print(corrected_processing_time);
            // Serial.print(" - Corrected ToF: ");
            // Serial.println(corrected_tof);

            msg_index += 1;
            curr_stage = 3;
            // Distance in cm
            distance = 100 * corrected_tof * DWT_TIME_UNITS * SPEED_OF_LIGHT / 2;
            Serial.println(distance);

          }
          else {
            // If the message was not meant for this anchor, clear the good frame received flag
            Serial.println("There is an error in the protocol!");
            dwt_write32bitreg(SYS_STATUS_ID, SYS_STATUS_ALL_RX_TO | SYS_STATUS_ALL_RX_ERR);
            curr_stage = 0;
          }
        }
      }
      else {
        dwt_write32bitreg(SYS_STATUS_ID, SYS_STATUS_ALL_RX_TO | SYS_STATUS_ALL_RX_ERR);
        curr_stage = 0;
      }
      break;
    }
    case 3: {
      // Transmitting clearance message
      delay(1);
      tx_ping_msg[SENDER_ID_IDX] = DEVICE_ID;
      tx_ping_msg[RECEIVER_ID_IDX] = OTHER_ANCHOR_ID;
      tx_ping_msg[MESSAGE_NUMBER_IDX] = msg_index;
      tx_ping_msg[MESSAGE_TYPE_IDX] = CLEARANCE_MESSAGE;

      // Clear Tx status flag
      dwt_write32bitreg(SYS_STATUS_ID, SYS_STATUS_TXFRS_BIT_MASK);

      // Transmitting the data and correcting for buffer offset
      dwt_writetxdata(sizeof(tx_ping_msg), tx_ping_msg, 0);
      dwt_writetxfctrl(sizeof(tx_ping_msg), 0, 1);
      
      // Immediately start transmission along with response flag expected
      dwt_starttx(DWT_START_TX_IMMEDIATE | DWT_RESPONSE_EXPECTED);
      // Serial.println("Waiting for transmission");

      /// Waiting for transmission to complete
      while (!(dwt_read32bitreg(SYS_STATUS_ID) & SYS_STATUS_TXFRS_BIT_MASK)) {
        // Do nothing
      }
      // Serial.println("Clearance message transmitted!");
      curr_stage = 4;
      start_time = millis();
      break;
    }
    case 4: {
      // delay(1000);
      // Serial.println("Waiting for message reception!");
      // curr_stage = 4;
      dwt_rxenable(DWT_START_RX_IMMEDIATE);
      start_time = millis();
      
      // Clear the transmitted flag
      dwt_write32bitreg(SYS_STATUS_ID, SYS_STATUS_TXFRS_BIT_MASK);
      
      while (!((status_reg = dwt_read32bitreg(SYS_STATUS_ID)) & (SYS_STATUS_RXFCG_BIT_MASK | SYS_STATUS_ALL_RX_ERR))) {
        // polling
        if (millis() - start_time > message_timeout) {
          curr_stage = 0;
          break;
        }
      }
      if (curr_stage == 0) {
        Serial.println("Message timeout, transmitting new ping message");
        ESP.restart();
        break;
      }

      // If a good frame is received
      if (status_reg & SYS_STATUS_RXFCG_BIT_MASK) {
        // Compute frame length for received frame
        uint32_t frame_len;

        // Clear the good frame received flag
        dwt_write32bitreg(SYS_STATUS_ID, SYS_STATUS_RXFCG_BIT_MASK);

        // Reading the frame
        frame_len = dwt_read32bitreg(RX_FINFO_ID) & RXFLEN_MASK;
        if (frame_len <= sizeof(rx_buffer)) {
          // Putting the frame into buffer
          dwt_readrxdata(rx_buffer, frame_len, 0);

          if (rx_buffer[SENDER_ID_IDX] == OTHER_ANCHOR_ID && rx_buffer[RECEIVER_ID_IDX] == DEVICE_ID && rx_buffer[MESSAGE_TYPE_IDX] == CLEARANCE_MESSAGE) {
            // Serial.println("Clearance message received!");
            curr_stage = 0;
            delay(MEASUREMENT_INTERVAL);
          }
          else {
            // If the message was not meant for this anchor, clear the good frame received flag
            // Serial.println("Message not meant for this tag!");
            dwt_write32bitreg(SYS_STATUS_ID, SYS_STATUS_ALL_RX_TO | SYS_STATUS_ALL_RX_ERR);
            curr_stage = 4;
          }
        }
      }
      break;
    }
  }
  // // Delay between messages sent
  // msg_index += 1;
  // delay(1000);
}

// ToF: 31683052 - Processing Time: 31683093.00 - Adjusted ToF: -41.00

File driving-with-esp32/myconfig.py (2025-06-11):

CAMERA_TYPE="MOCK"
CAMERA_INDEX = 0  # used for 'WEBCAM' and 'CVCAM' when there is more than one camera connected 
DRIVE_TRAIN_TYPE = "VESC"
VESC_MAX_SPEED_PERCENT =.2 ## Max speed as a percent of actual max speed 
VESC_SERIAL_PORT= "/dev/ttyACM0" ## check this val with ls /dev/tty* 
VESC_HAS_SENSOR= True 
VESC_START_HEARTBEAT= True 
VESC_BAUDRATE= 115200 
VESC_TIMEOUT= 0.05 
VESC_STEERING_SCALE = .5
VESC_STEERING_OFFSET = .5
DONKEY_GYM = False

USE_JOYSTICK_AS_DEFAULT = True      #when starting the manage.py, when True, will not require a --js option to use the joystick
JOYSTICK_MAX_THROTTLE = 0.6         #this scalar is multiplied with the -1 to 1 throttle value to limit the maximum throttle. This can help if you drop the controller or just don't need the full speed available.
JOYSTICK_STEERING_SCALE = 1.0       #some people want a sateering that is less sensitve. This scalar is multiplied with the steering -1 to 1. It can be negative to reverse dir.
AUTO_RECORD_ON_THROTTLE = False      #if true, we will record whenever throttle is not zero. if false, you must manually toggle recording with some other trigger. Usually circle button on joystick.
CONTROLLER_TYPE = 'F710'            #(ps3|ps4|xbox|pigpio_rc|nimbus|wiiu|F710|rc3|MM1|custom) custom will run the my_joystick.py controller written by the `donkey createjs` command
PATH_SCALE = 25.0                    # the path display will be scaled by this factor in the web page
PATH_OFFSET = (0, 0)                # 255, 255 is the center of the map. This offset controls where the origin is displayed.
PATH_MIN_DIST = 0.01                 # after travelling this distance (m), save a path point
PID_P = 0.03                   # proportional mult for PID path followe
PID_I = 0.0                       # integral mul:w for PID path follower
PID_D = 0.15                     # differential mult for PID path follower
PID_THROTTLE = 0.3                  # constant throttle value during path following
GPS_SERIAL="/dev/ttyUSB2"
GPS_SERIAL_BAUDRATE = 38400 #ublox
GPS_DEBUG = True
# HAVE_GPS = True
HAVE_GPS = False
GPS_NMEA_PATH = None
SAVE_PATH_BTN = "Y"    	# button to save path
LOAD_PATH_BTN = "X"         	# button (re)load path
RESET_ORIGIN_BTN = "B" 	# button to press to move car back to origin
ERASE_PATH_BTN = None 	# button to erase path
TOGGLE_RECORDING_BTN = "A" # button to toggle recording mode
INC_PID_D_BTN = None        	# button to change PID 'D' constant by PID_D_DELTA
DEC_PID_D_BTN = None        	# button to change PID 'D' constant by -PID_D_DELTA
INC_PID_P_BTN = None        	# button to change PID 'P' constant by PID_P_DELTA
DEC_PID_P_BTN = None        	# button to change PID 'P' constant by -PID_P_DELTA
PATH_SEARCH_LENGTH = 10   # number of points to search for closest point, None to search entire path
PATH_LOOK_AHEAD = 4         # number of points ahead of the closest point to include in cte track
PATH_LOOK_BEHIND = 4        # number of points behind the closest point to include in cte track   
PID_D_DELTA = 0.1
PID_P_DELTA = 0.1
ESP32_PORT1 = "/dev/ttyUSB0"
ESP32_PORT2 = "/dev/ttyUSB1"
IMU_PORT = "/dev/ttyACM1"
QUEUE_SIZE = 10
# ANCHOR_DISTANCE = 0.37
ANCHOR_DISTANCE = 0.71
PLOT_LIMIT_FACTOR = 10.0
REFRESH_RATE = 0.01
BAUD_RATE = 115200
WAYPOINTS_PER_METER = 10
DISTANCE_THRESHOLD = 10.0
PID_THROTTLE_DECELERATE = 0.1 # Percentage of the waypoints to decelerate when the path is reaching completion.
PATH_CURVE_FACTOR = 1.5 # Use this to control the curvature of the path. Higher values mean lower curvature.

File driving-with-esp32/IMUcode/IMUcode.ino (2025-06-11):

/*****************************************************************************/
//  HighLevelExample.ino
//  Hardware:      Grove - 6-Axis Accelerometer&Gyroscope
//	Arduino IDE:   Arduino-1.65
//	Author:	       Lambor
//	Date: 	       Oct,2015
//	Version:       v1.0
//
//  Modified by:
//  Data:
//  Description:
//
//	by www.seeedstudio.com
//
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
/*******************************************************************************/

#include <Arduino.h>
#include "LSM6DS3.h"
//#include <SparkFunLSM6DS3.h> 
#include "Wire.h"

//Create a instance of class LSM6DS3
LSM6DS3 myIMU(I2C_MODE, 0x6A);    //I2C device address 0x6A
float yaw = 0.0;          // Yaw angle (in degrees)
unsigned long prevTime = 0;

void setup() {
    // put your setup code here, to run once:
    Serial.begin(115200);
    yaw = 0.0;  
    while (!Serial);
    //Call .begin() to configure the IMUs
    if (myIMU.begin() != 0) {
        Serial.println("Device error");
    } else {
        Serial.println("Device OK!");
    }

}

void loop() {
 
   if (Serial.available()) {
    String cmd = Serial.readStringUntil('\n');
    cmd.trim(); // Remove whitespace

    if (cmd == "RESET") {
      Serial.println("Resetting...");
      delay(100);  // Give time to send response
      // NVIC_SystemReset();  // Perform software reset
      yaw = 0.0;
    }
  }
  
    float ax = myIMU.readFloatAccelX();
    float ay = myIMU.readFloatAccelY();
    float az = myIMU.readFloatAccelZ();
    float gx = myIMU.readFloatGyroX();
    float gy = myIMU.readFloatGyroY();
    float gz = myIMU.readFloatGyroZ();

    /*
    Serial.print("gx:"); Serial.print(gx); Serial.print("\t");
    Serial.print("gy:"); Serial.print(gy); Serial.print("\t");
    Serial.print("gz:"); Serial.println(gz);
    */
    unsigned long currentTime = millis();
    float dt = (currentTime - prevTime) / 1000.0;
    prevTime = currentTime;
    if(gz < 1 && gz > -1) gz = 0;

    // Integrate gyroZ over time to get yaw angle
    yaw += gz * dt;

     // Normalize yaw to -180 to 180 degrees
     if (yaw > 180.0) yaw -= 360.0;
     if (yaw < -180.0) yaw += 360.0;


    // Convert to 0–360 range
    if (yaw < 0) yaw += 360.0;

    // Serial.print("gz:"); Serial.print(gz);
    // Serial.print("Yaw (Δθ): "); Serial.println(yaw, 2);  // Print yaw with 2 decimal places
    Serial.println(yaw, 2);
    delay(50); 
}

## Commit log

2025-06-10 Rename mae148 wiring.png to mae148wiring.png
2025-06-10 Rename OAK-D Lite Adapter.3mf to OAK-DLiteAdapter.3mf
    [OAK-DLiteAdapter.3mf]
2025-06-11 Adding Images and Re-ordering
    [Electronics Mount Plate v1.dxf, NanoBox_Bottom_v21.stl, NanoBox_Top_v22.stl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]
2025-06-12 Re-ordering directories
    [Electronics Mount Plate v1.dxf, NanoBox_Bottom_v21.stl, NanoBox_Top_v22.stl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]
2025-06-13 ESP32 code explanation
2025-06-13 ESP32 code documentation and step-by-step running
